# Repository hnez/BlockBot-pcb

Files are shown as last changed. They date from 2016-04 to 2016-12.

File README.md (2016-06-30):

BlockBot - Housing 3D-Designs
=============================

This repository contains all PCB design files.

All designs are created with the KiCad EDA suite.

The directory structure is as follow:

- blocks - Brick PCB
- dk_base - Millable PCB for the "denmark base" robot
- panel - Panelized layout that combines bricks and remote into a single file for cheaper ordering
- remote - Collector unit PCB

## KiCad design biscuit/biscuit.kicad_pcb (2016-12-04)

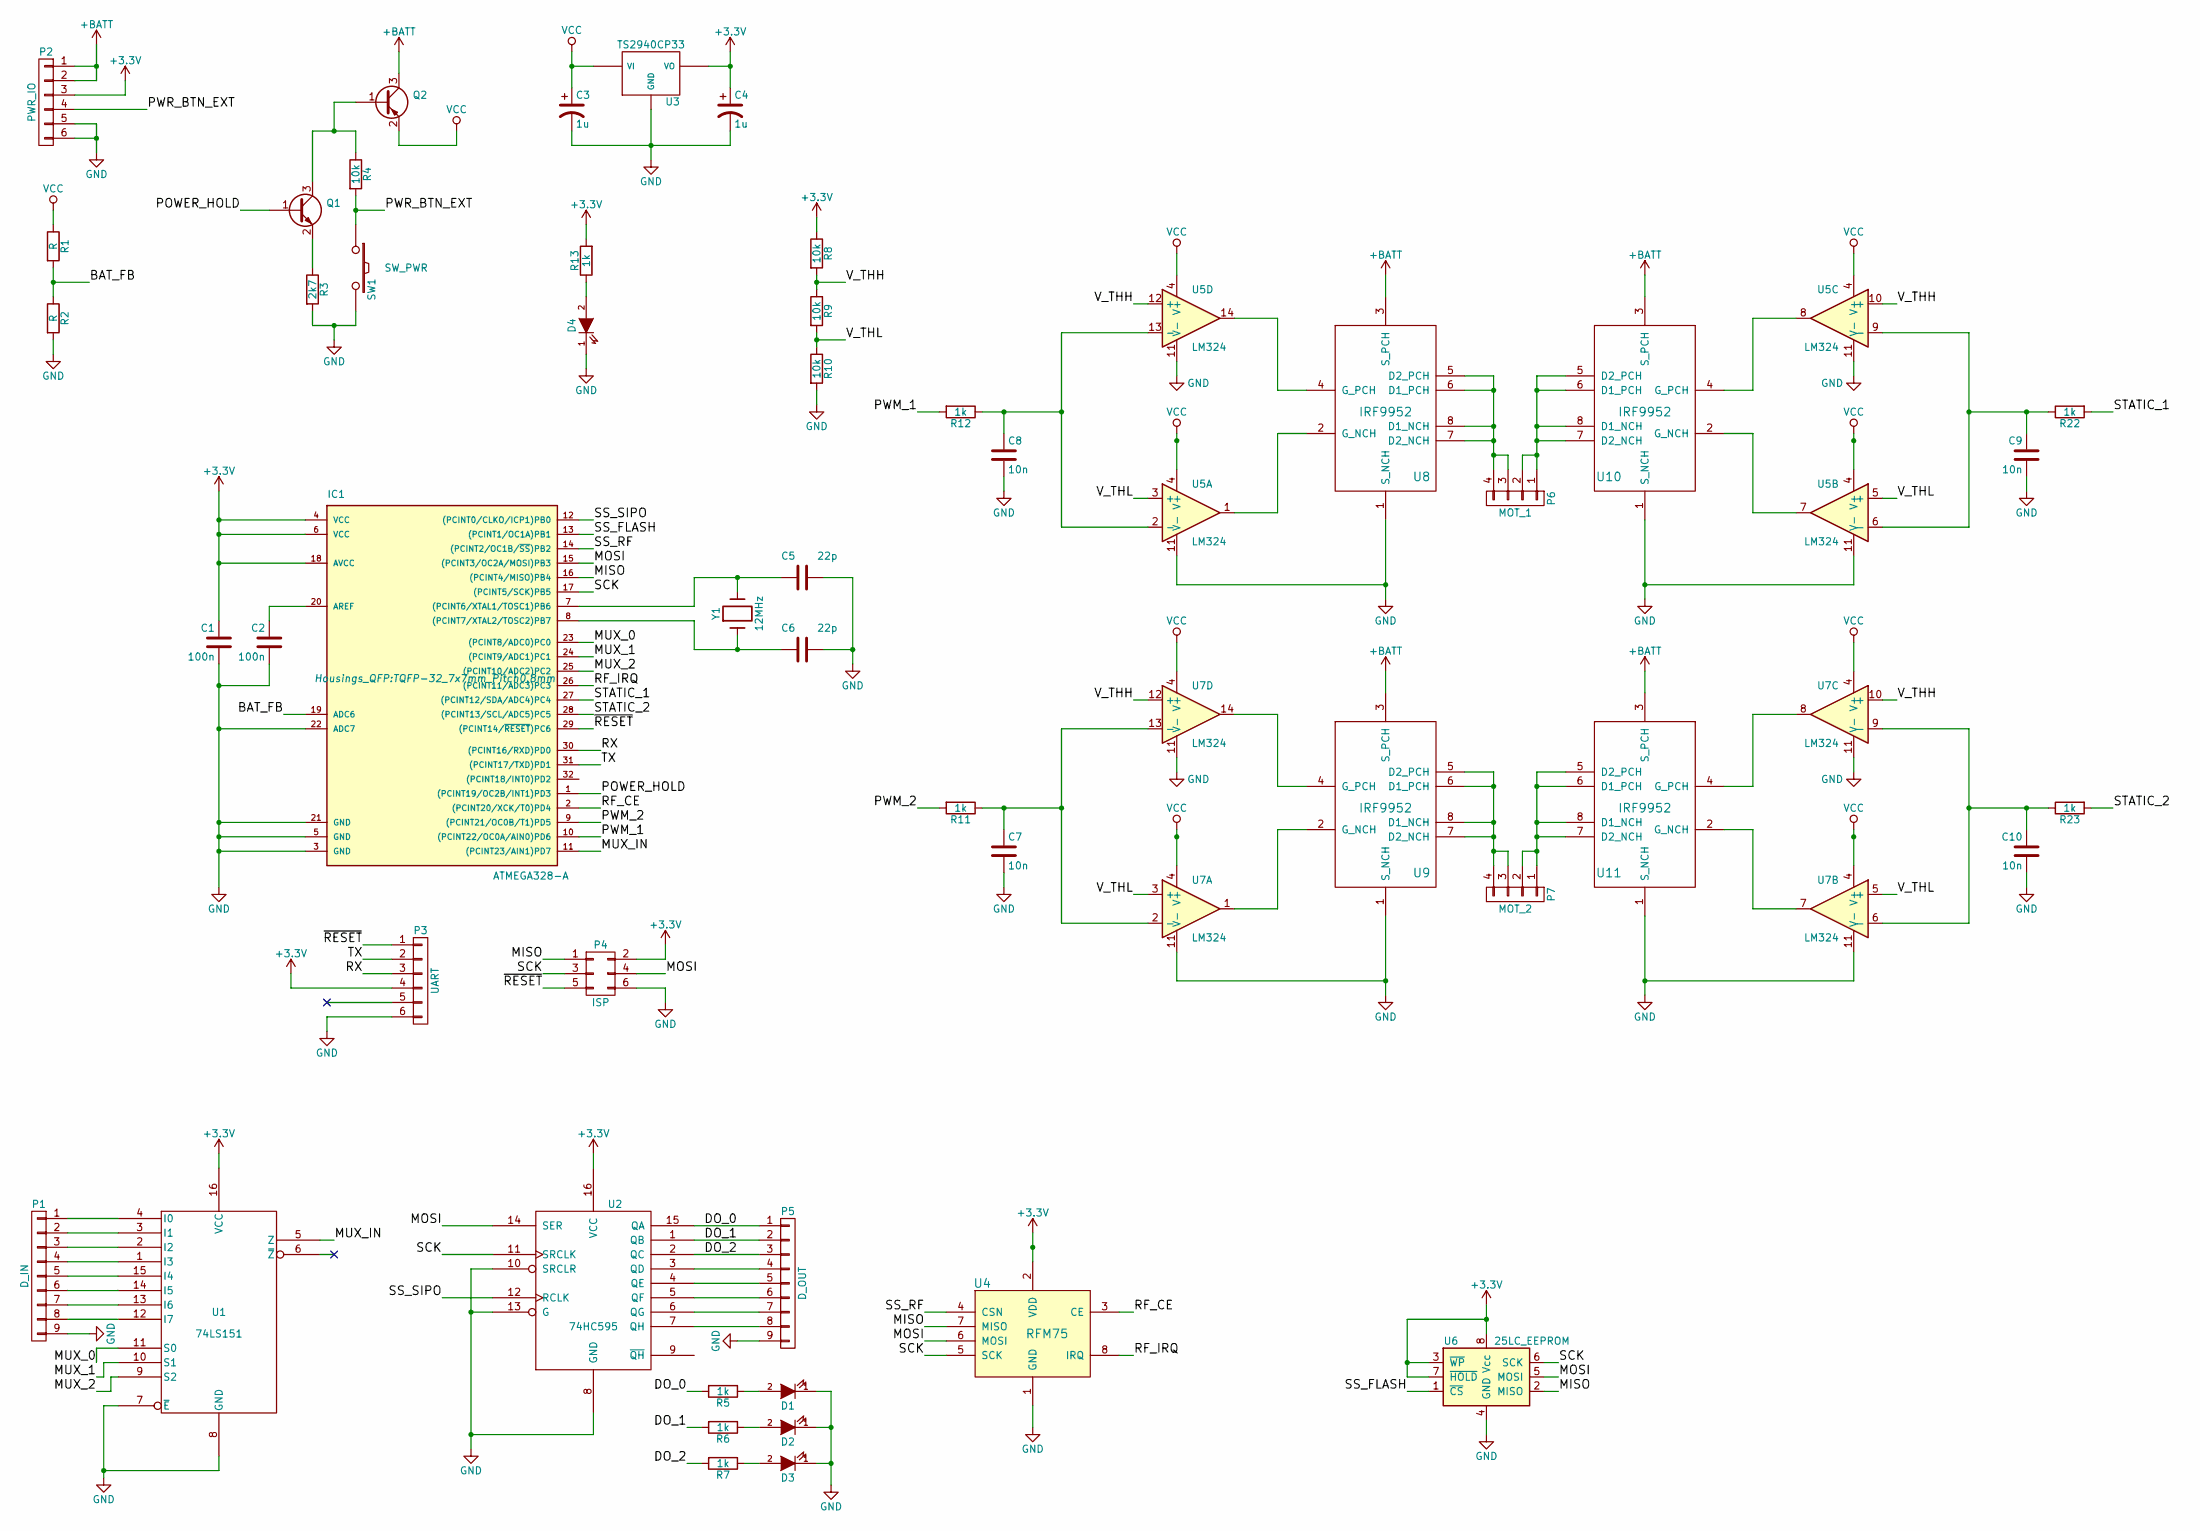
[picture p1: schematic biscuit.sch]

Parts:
C1, C2: 100n; C_0805
C3, C4: 1u; TantalC_SizeA_EIA-3216_Reflow
C5, C6: 22p; C_0805
C7, C8, C9, C10: 10n; C_0805
D1, D2, D3, D4: LED; LED_0805
IC1: ATMEGA328-A; TQFP-32_7x7mm_Pitch0.8mm
P1: D_IN; Pin_Header_Straight_1x09
P2: PWR_IO; Pin_Header_Straight_1x06
P3: UART; Pin_Header_Straight_1x06
P4: ISP; Pin_Header_Straight_2x03
P5: D_OUT; Pin_Header_Straight_1x09
P6: MOT_1; Pin_Header_Straight_1x04
P7: MOT_2; Pin_Header_Straight_1x04
Q1: Q_NPN_BEC; SOT-23
Q2: Q_PNP_BEC; SOT-23
R1, R2: R; R_0805
R3: 2k7; R_0805
R4, R8, R9, R10: 10k; R_0805
R5, R6, R7, R11, R12, R13, R22, R23: 1k; R_0805
SW1: SW_PWR; Schurter_LSG_1301
U1: 74LS151; SO-16-N
U2: 74HC595; SO-16-N
U3: TS2940CP33; TO-252-2Lead
U4: RFM75
U5, U7: LM324; SOIC-14_N
U6: 25LC_EEPROM; SOIC-8-N
U8, U9, U10, U11: IRF9952; SOIC-8-N
Y1: 12MHz; Crystal_HC49-SD_SMD

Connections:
+3V3: C1.1, C4.1, IC1.4 (VCC), IC1.6 (VCC), IC1.18 (AVCC), P2.3, P3.4, P4.2, R8.1, R13.2, U1.16 (VCC), U2.16 (VCC), U3.3 (VO), U4.2 (VDD), U6.3 (~WP), U6.7 (~HOLD), U6.8 (Vcc)
+BATT: P2.1, P2.2, Q2.3 (C), U8.3 (S_PCH), U9.3 (S_PCH), U10.3 (S_PCH), U11.3 (S_PCH)
/BAT_FB: IC1.19 (ADC6), R1.2, R2.1
/DO_0: P5.1, R5.2, U2.15 (QA)
/DO_1: P5.2, R6.2, U2.1 (QB)
/DO_2: P5.3, R7.2, U2.2 (QC)
/MISO: IC1.16 ((PCINT4/MISO)PB4), P4.1, U4.7 (MISO), U6.2 (MISO)
/MOSI: IC1.15 ((PCINT3/OC2A/MOSI)PB3), P4.4, U2.14 (SER), U4.6 (MOSI), U6.5 (MOSI)
/MUX_0: IC1.23 ((PCINT8/ADC0)PC0), U1.11 (S0)
/MUX_1: IC1.24 ((PCINT9/ADC1)PC1), U1.10 (S1)
/MUX_2: IC1.25 ((PCINT10/ADC2)PC2), U1.9 (S2)
/MUX_IN: IC1.11 ((PCINT23/AIN1)PD7), U1.5 (Z)
/POWER_HOLD: IC1.1 ((PCINT19/OC2B/INT1)PD3), Q1.1 (B)
/PWM_1: IC1.10 ((PCINT22/OC0A/AIN0)PD6), R12.2
/PWM_2: IC1.9 ((PCINT21/OC0B/T1)PD5), R11.2
/PWR_BTN_EXT: P2.4, R4.2, SW1.1
/RF_CE: IC1.2 ((PCINT20/XCK/T0)PD4), U4.3 (CE)
/RF_IRQ: IC1.26 ((PCINT11/ADC3)PC3), U4.8 (IRQ)
/RX: IC1.30 ((PCINT16/RXD)PD0), P3.3
/SCK: IC1.17 ((PCINT5/SCK)PB5), P4.3, U2.11 (SRCLK), U4.5 (SCK), U6.6 (SCK)
/SS_FLASH: IC1.13 ((PCINT1/OC1A)PB1), U6.1 (~CS)
/SS_RF: IC1.14 ((PCINT2/OC1B/~SS~)PB2), U4.4 (CSN)
/SS_SIPO: IC1.12 ((PCINT0/CLKO/ICP1)PB0), U2.12 (RCLK)
/STATIC_1: IC1.27 ((PCINT12/SDA/ADC4)PC4), R22.2
/STATIC_2: IC1.28 ((PCINT13/SCL/ADC5)PC5), R23.2
/TX: IC1.31 ((PCINT17/TXD)PD1), P3.2
/V_THH: R8.2, R9.1, U5.10 (+), U5.12 (+), U7.10 (+), U7.12 (+)
/V_THL: R9.2, R10.1, U5.3 (+), U5.5 (+), U7.3 (+), U7.5 (+)
/~RESET: IC1.29 ((PCINT14/~RESET~)PC6), P3.1, P4.5
GND: C1.2, C2.2, C3.2, C4.2, C5.1, C6.1, C7.2, C8.2, C9.2, C10.2, D1.1 (K), D2.1 (K), D3.1 (K), D4.1 (K), IC1.3 (GND), IC1.5 (GND), IC1.21 (GND), IC1.22 (ADC7), P1.9, P2.5, P2.6, P3.6, P4.6, P5.9, R2.2, R3.2, R10.2, SW1.2, U1.7 (~E), U1.8 (GND), U2.8 (GND), U2.10 (SRCLR), U2.13 (G), U3.2 (GND), U4.1 (GND), U5.11 (V-), U6.4 (GND), U7.11 (V-), U8.1 (S_NCH), U9.1 (S_NCH), U10.1 (S_NCH), U11.1 (S_NCH)
unnamed: C2.1, IC1.20 (AREF)
unnamed: C5.2, IC1.7 ((PCINT6/XTAL1/TOSC1)PB6), Y1.2
unnamed: C6.2, IC1.8 ((PCINT7/XTAL2/TOSC2)PB7), Y1.1
unnamed: C7.1, R11.1, U7.2 (-), U7.13 (-)
unnamed: C8.1, R12.1, U5.2 (-), U5.13 (-)
unnamed: C9.1, R22.1, U5.6 (-), U5.9 (-)
unnamed: C10.1, R23.1, U7.6 (-), U7.9 (-)
unnamed: D1.2 (A), R5.1
unnamed: D2.2 (A), R6.1
unnamed: D3.2 (A), R7.1
unnamed: D4.2 (A), R13.1
unnamed: P1.1, U1.4 (I0)
unnamed: P1.2, U1.3 (I1)
unnamed: P1.3, U1.2 (I2)
unnamed: P1.4, U1.1 (I3)
unnamed: P1.5, U1.15 (I4)
unnamed: P1.6, U1.14 (I5)
unnamed: P1.7, U1.13 (I6)
unnamed: P1.8, U1.12 (I7)
unnamed: P5.4, U2.3 (QD)
unnamed: P5.5, U2.4 (QE)
unnamed: P5.6, U2.5 (QF)
unnamed: P5.7, U2.6 (QG)
unnamed: P5.8, U2.7 (QH)
unnamed: P6.1, P6.2, U10.5 (D2_PCH), U10.6 (D1_PCH), U10.7 (D2_NCH), U10.8 (D1_NCH)
unnamed: P6.3, P6.4, U8.5 (D2_PCH), U8.6 (D1_PCH), U8.7 (D2_NCH), U8.8 (D1_NCH)
unnamed: P7.1, P7.2, U11.5 (D2_PCH), U11.6 (D1_PCH), U11.7 (D2_NCH), U11.8 (D1_NCH)
unnamed: P7.3, P7.4, U9.5 (D2_PCH), U9.6 (D1_PCH), U9.7 (D2_NCH), U9.8 (D1_NCH)
unnamed: Q1.2 (E), R3.1
unnamed: Q1.3 (C), Q2.1 (B), R4.1
unnamed: U5.1, U8.2 (G_NCH)
unnamed: U5.14, U8.4 (G_PCH)
unnamed: U7.1, U9.2 (G_NCH)
unnamed: U7.14, U9.4 (G_PCH)
unnamed: U5.7, U10.2 (G_NCH)
unnamed: U5.8, U10.4 (G_PCH)
unnamed: U7.7, U11.2 (G_NCH)
unnamed: U7.8, U11.4 (G_PCH)
VCC: C3.1, Q2.2 (E), R1.1, U3.1 (VI), U5.4 (V+), U7.4 (V+)

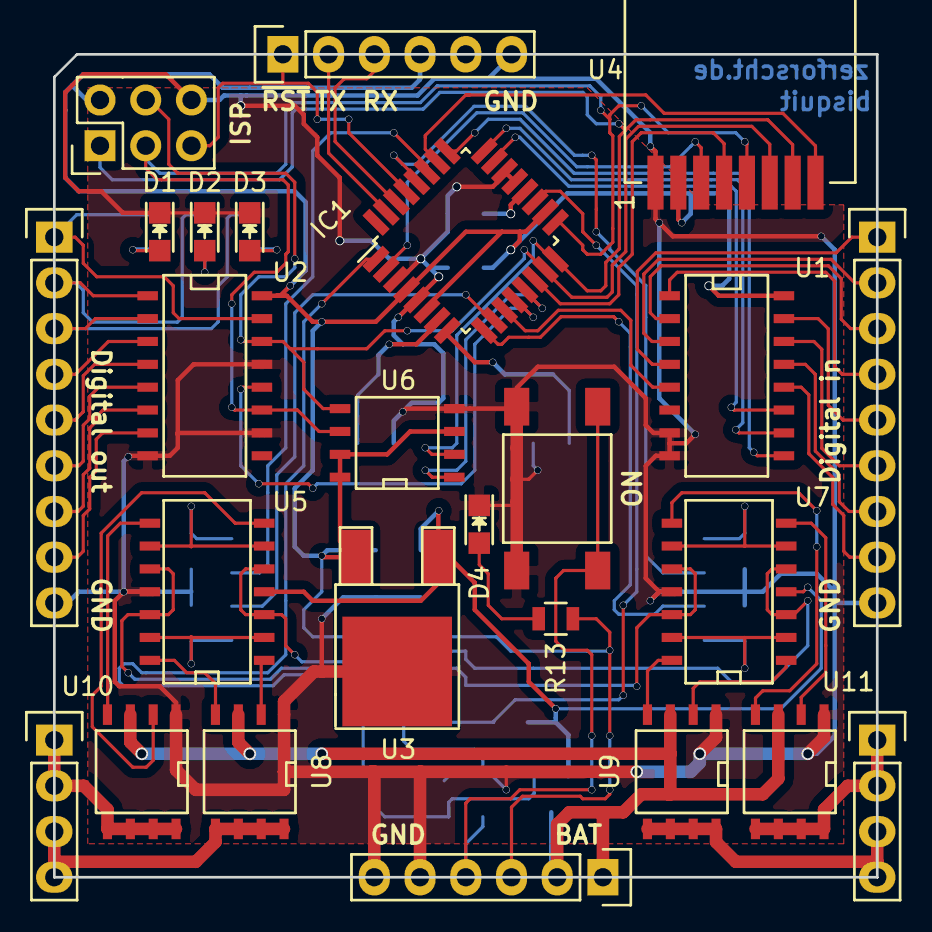
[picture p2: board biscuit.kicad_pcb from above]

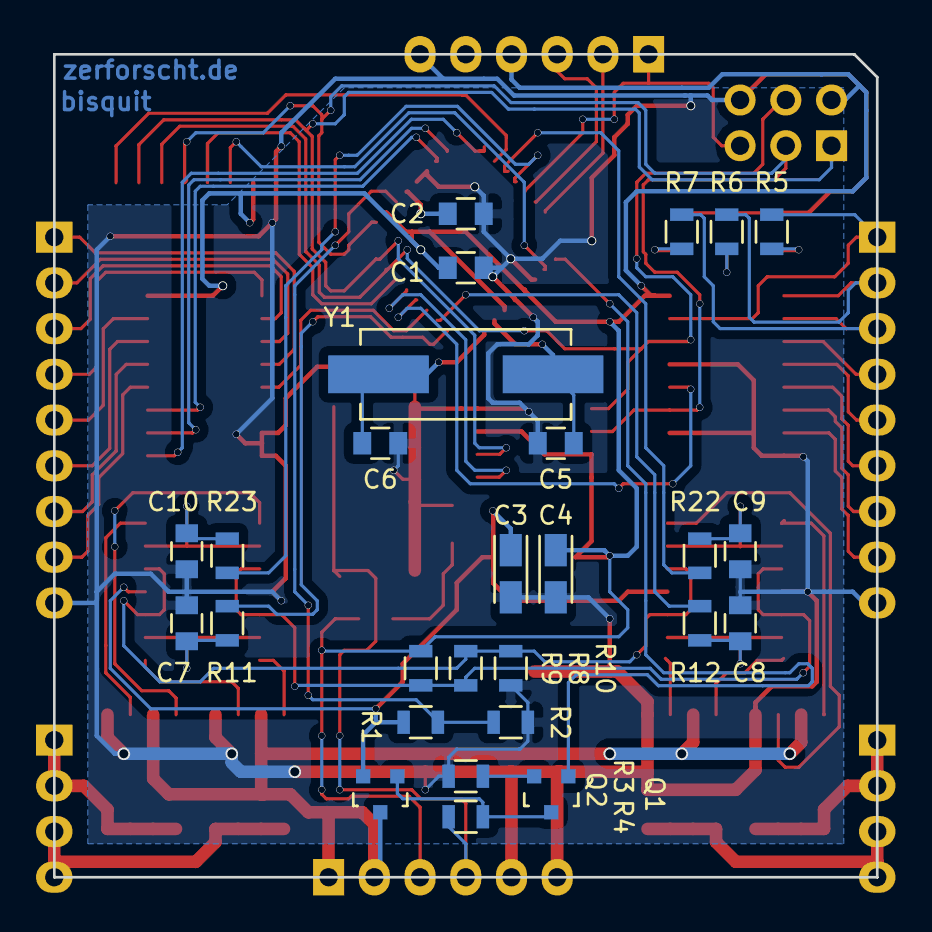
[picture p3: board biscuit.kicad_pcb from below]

Board: 2 copper layers, 45.7 x 45.7 mm, 52 parts (27 on the bottom side), 69 nets.

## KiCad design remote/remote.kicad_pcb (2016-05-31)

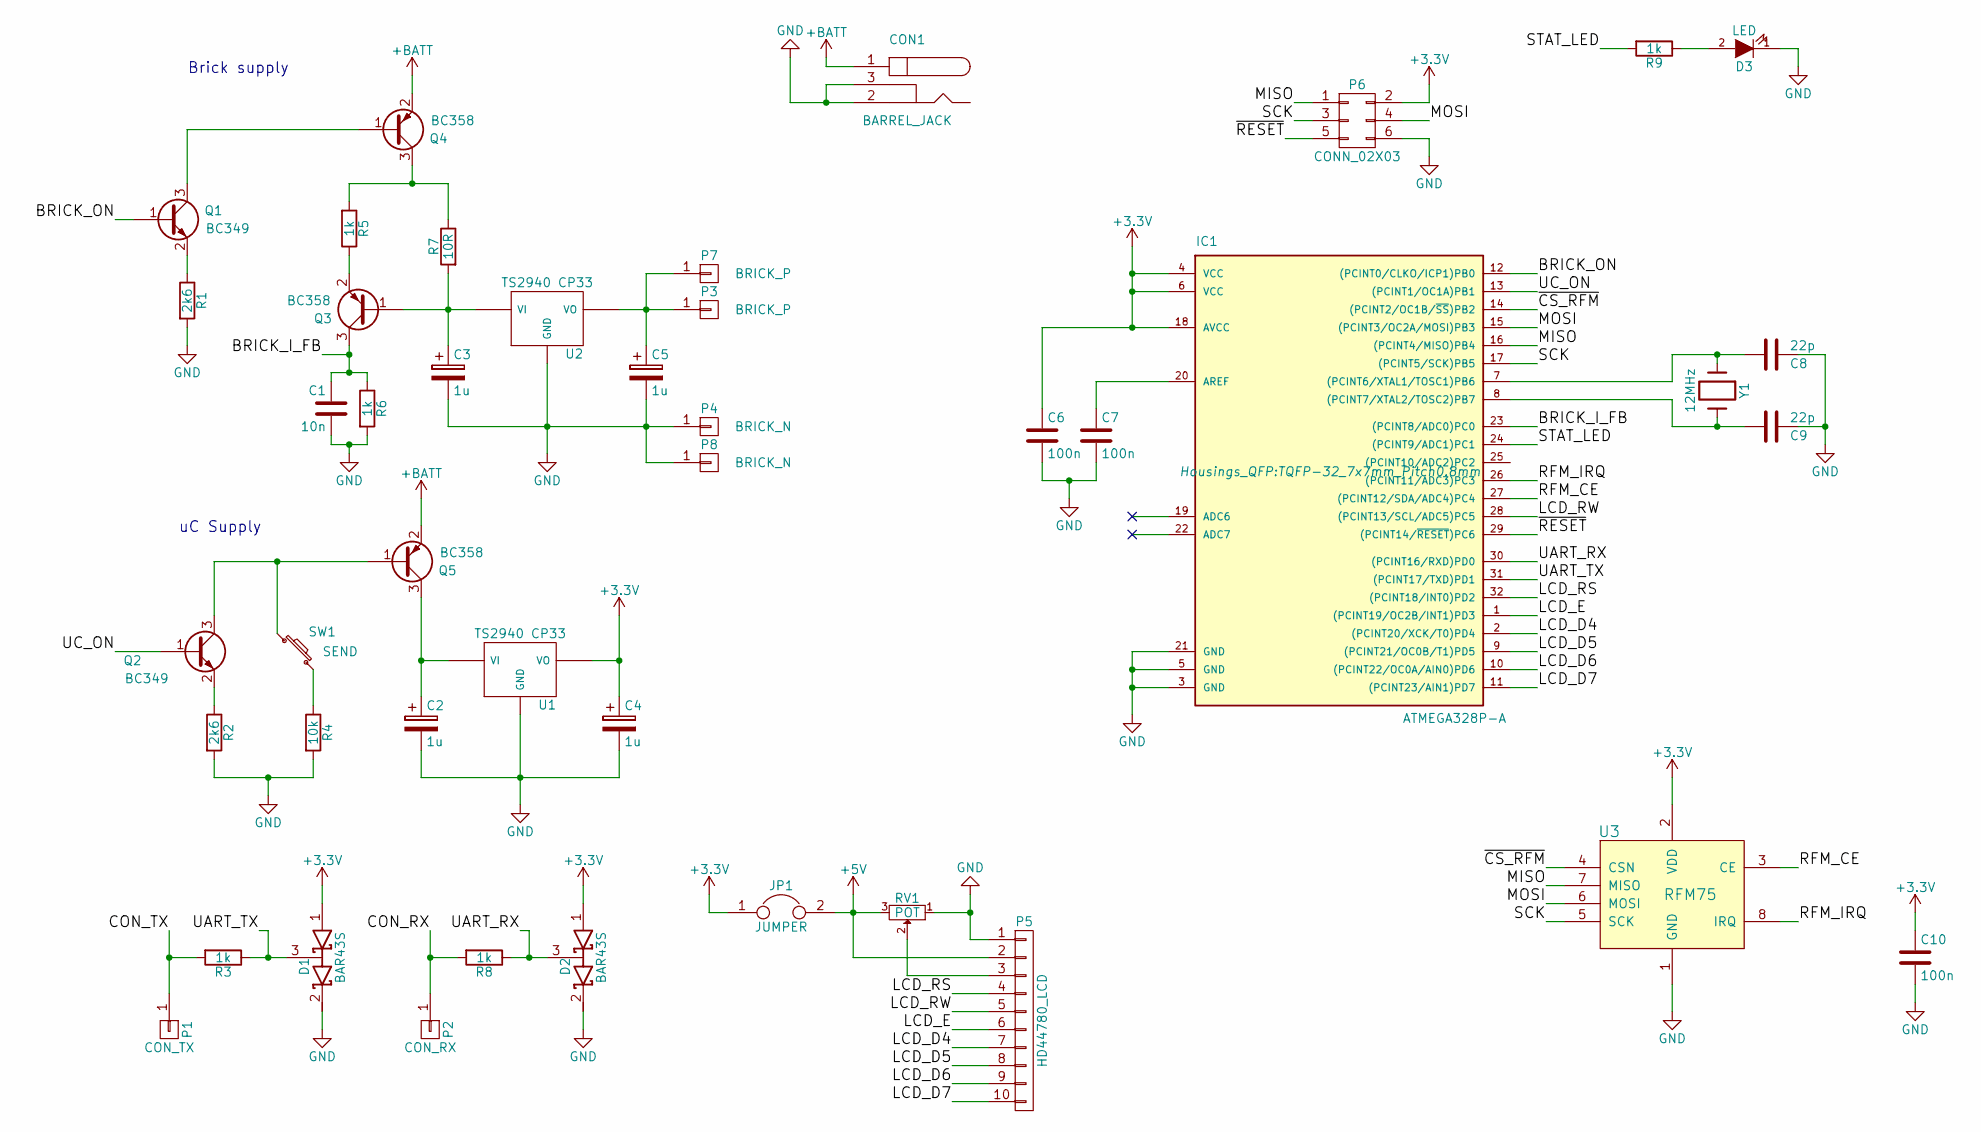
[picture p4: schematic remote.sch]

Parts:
C1: 10n; C_0805_HandSoldering
C2, C3, C4, C5: 1u; TantalC_SizeA_EIA-3216_HandSoldering
C6, C7, C10: 100n; C_0805_HandSoldering
C8, C9: 22p; C_0805_HandSoldering
CON1: BARREL_JACK
D1, D2: BAR43S; SOT-23
D3: LED; LED-3MM
IC1: ATMEGA328P-A; TQFP-32_7x7mm_Pitch0.8mm
JP1: JUMPER; R_0805_HandSoldering
P1: CON_TX; SmallFoilCon
P2: CON_RX; SmallFoilCon
P3, P7: BRICK_P; SmallFoilCon
P4, P8: BRICK_N; BigFoilCon
P5: HD44780_LCD; Pin_Header_Straight_1x10
P6: CONN_02X03; Pin_Header_Straight_2x03
Q1, Q2: BC349; SOT-23
Q3, Q4, Q5: BC358; SOT-23
R1, R2: 2k6; R_0805_HandSoldering
R3, R5, R6, R8, R9: 1k; R_0805_HandSoldering
R4: 10k; R_0805_HandSoldering
R7: 10R; R_0805_HandSoldering
RV1: POT; Cermet_Model23
SW1: SEND; Schurter_LSG_1301
U1, U2: TS2940 CP33; TO-252-2Lead
U3: RFM75
Y1: 12MHz; Crystal_HC49-U_Vertical

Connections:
+3V3: C4.1, C6.1, C10.1, D1.1 (A), D2.1 (A), IC1.4 (VCC), IC1.6 (VCC), IC1.18 (AVCC), JP1.1, P6.2, U1.VO, U3.2 (VDD)
+5V: JP1.2, P5.2, RV1.3
+BATT: CON1.1, Q4.2 (E), Q5.2 (E)
/BRICK_I_FB: C1.1, IC1.23 ((PCINT8/ADC0)PC0), Q3.3 (C), R6.1
/BRICK_ON: IC1.12 ((PCINT0/CLKO/ICP1)PB0), Q1.1 (B)
/CON_RX: P2.1, R8.2
/CON_TX: P1.1, R3.2
/LCD_D4: IC1.2 ((PCINT20/XCK/T0)PD4), P5.7
/LCD_D5: IC1.9 ((PCINT21/OC0B/T1)PD5), P5.8
/LCD_D6: IC1.10 ((PCINT22/OC0A/AIN0)PD6), P5.9
/LCD_D7: IC1.11 ((PCINT23/AIN1)PD7), P5.10
/LCD_E: IC1.1 ((PCINT19/OC2B/INT1)PD3), P5.6
/LCD_RS: IC1.32 ((PCINT18/INT0)PD2), P5.4
/LCD_RW: IC1.28 ((PCINT13/SCL/ADC5)PC5), P5.5
/MISO: IC1.16 ((PCINT4/MISO)PB4), P6.1, U3.7 (MISO)
/MOSI: IC1.15 ((PCINT3/OC2A/MOSI)PB3), P6.4, U3.6 (MOSI)
/RFM_CE: IC1.27 ((PCINT12/SDA/ADC4)PC4), U3.3 (CE)
/RFM_IRQ: IC1.26 ((PCINT11/ADC3)PC3), U3.8 (IRQ)
/SCK: IC1.17 ((PCINT5/SCK)PB5), P6.3, U3.5 (SCK)
/STAT_LED: IC1.24 ((PCINT9/ADC1)PC1), R9.2
/UART_RX: D2.3 (common), IC1.30 ((PCINT16/RXD)PD0), R8.1
/UART_TX: D1.3 (common), IC1.31 ((PCINT17/TXD)PD1), R3.1
/UC_ON: IC1.13 ((PCINT1/OC1A)PB1), Q2.1 (B)
/~CS_RFM: IC1.14 ((PCINT2/OC1B/~SS~)PB2), U3.4 (CSN)
/~RESET: IC1.29 ((PCINT14/~RESET~)PC6), P6.5
GND: C1.2, C2.2, C3.2, C4.2, C5.2, C6.2, C7.2, C8.1, C9.1, C10.2, CON1.2, CON1.3, D1.2 (K), D2.2 (K), D3.1 (K), IC1.3 (GND), IC1.5 (GND), IC1.21 (GND), P4.1, P5.1, P6.6, P8.1, R1.2, R2.2, R4.2, R6.2, RV1.1, U1.GND, U2.GND, U3.1 (GND)
unnamed: C2.1, Q5.3 (C), U1.VI
unnamed: C3.1, Q3.1 (B), R7.2, U2.VI
unnamed: C5.1, P3.1, P7.1, U2.VO
unnamed: C7.1, IC1.20 (AREF)
unnamed: C8.2, IC1.7 ((PCINT6/XTAL1/TOSC1)PB6), Y1.1
unnamed: C9.2, IC1.8 ((PCINT7/XTAL2/TOSC2)PB7), Y1.2
unnamed: D3.2 (A), R9.1
unnamed: P5.3, RV1.2
unnamed: Q1.2 (E), R1.1
unnamed: Q1.3 (C), Q4.1 (B)
unnamed: Q2.2 (E), R2.1
unnamed: Q2.3 (C), Q5.1 (B), SW1.1
unnamed: Q3.2 (E), R5.1
unnamed: Q4.3 (C), R5.2, R7.1
unnamed: R4.1, SW1.2

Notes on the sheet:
Brick supply
uC Supply

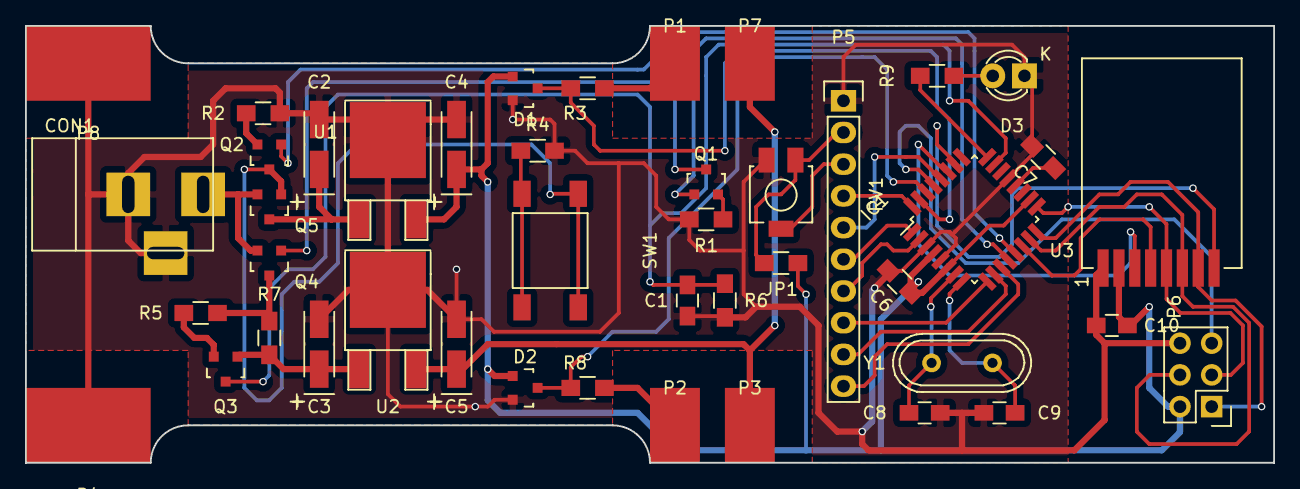
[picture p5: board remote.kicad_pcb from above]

Board: 2 copper layers, 100.0 x 35.0 mm, 44 parts (0 on the bottom side), 41 nets.

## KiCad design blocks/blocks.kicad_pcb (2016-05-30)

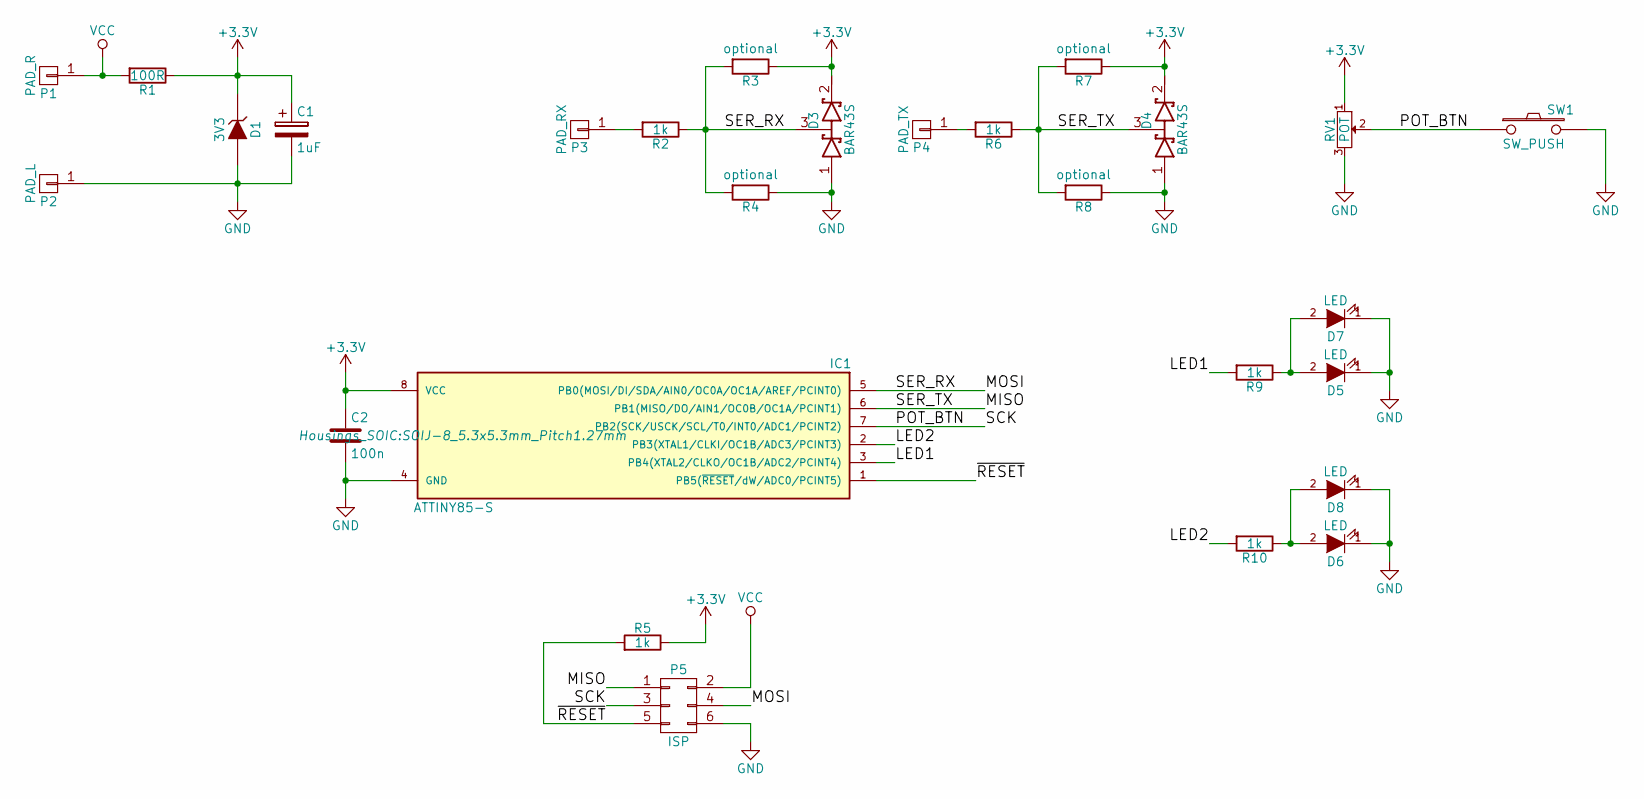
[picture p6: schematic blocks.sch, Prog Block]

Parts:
C1: 1uF; TantalC_SizeA_EIA-3216_HandSoldering
C2: 100n; C_0805_HandSoldering
D1: 3V3; SOT-23
D3, D4: BAR43S; SOT-23_Handsoldering
D5, D6: LED; LED-3MM
D7, D8: LED; LED_0805
IC1: ATTINY85-S; SOIJ-8_5.3x5.3mm_Pitch1.27mm
P1: PAD_R; BigPad
P2: PAD_L; HugePad
P3: PAD_RX; Smallpad
P4: PAD_TX; Smallpad
P5: ISP; Pin_Header_Straight_2x03
R1: 100R; R_0805_HandSoldering
R2, R5, R6, R9, R10: 1k; R_0805_HandSoldering
R3, R4, R7, R8: optional; R_0805_HandSoldering
RV1: POT; Cermet_Model23
SW1: SW_PUSH; Schurter_LSG_1301

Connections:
+3V3: C1.1, C2.1, D1.3 (K), D3.2 (K), D4.2 (K), IC1.8 (VCC), R1.1, R3.1, R5.1, R7.1, RV1.1
/LED1: IC1.3 (PB4(XTAL2/CLKO/OC1B/ADC2/PCINT4)), R9.2
/LED2: IC1.2 (PB3(XTAL1/CLKI/OC1B/ADC3/PCINT3)), R10.2
/MISO: D4.3 (common), IC1.6 (PB1(MISO/DO/AIN1/OC0B/OC1A/PCINT1)), P5.1, R6.1, R7.2, R8.2
/MOSI: D3.3 (common), IC1.5 (PB0(MOSI/DI/SDA/AIN0/OC0A/OC1A/AREF/PCI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), P5.4, R2.1, R3.2, R4.2
/POT_BTN: IC1.7 (PB2(SCK/USCK/SCL/T0/INT0/ADC1/PCINT2)), P5.3, RV1.2, SW1.1
/~RESET: IC1.1 (PB5(~RESET~/dW/ADC0/PCINT5)), P5.5, R5.2
GND: C1.2, C2.2, D1.1 (A), D3.1 (A), D4.1 (A), D5.1 (K), D6.1 (K), D7.1 (K), D8.1 (K), IC1.4 (GND), P2.1, P5.6, R4.1, R8.1, RV1.3, SW1.2
unnamed: D5.2 (A), D7.2 (A), R9.1
unnamed: D6.2 (A), D8.2 (A), R10.1
unnamed: P3.1, R2.2
unnamed: P4.1, R6.2
VCC: P1.1, P5.2, R1.2

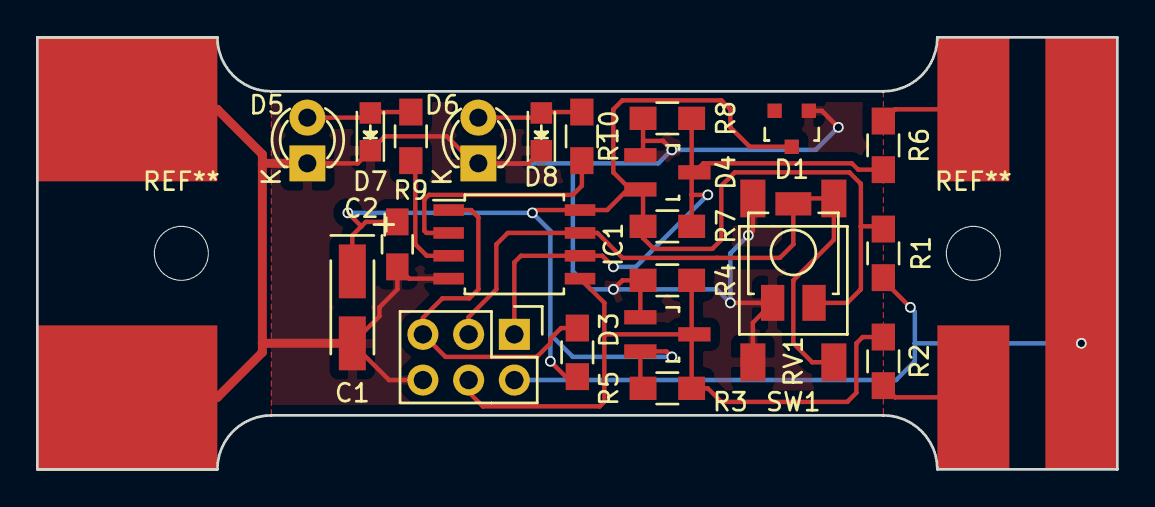
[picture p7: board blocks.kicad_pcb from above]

Board: 2 copper layers, 60.0 x 24.0 mm, 27 parts (0 on the bottom side), 13 nets.

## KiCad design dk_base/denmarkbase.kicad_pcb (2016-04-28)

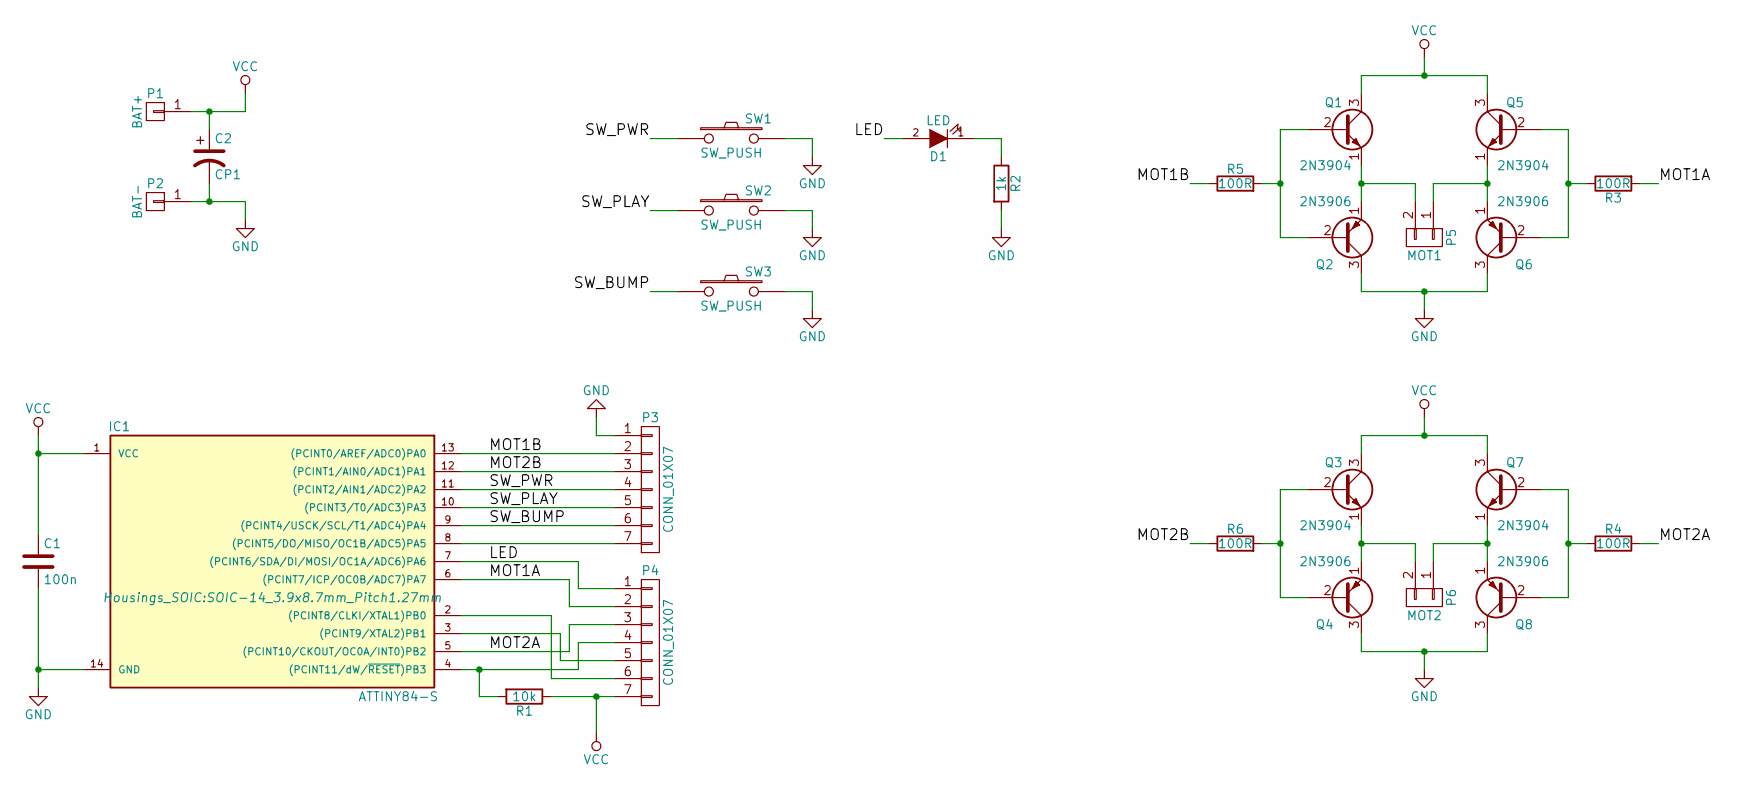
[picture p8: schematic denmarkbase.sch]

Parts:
C1: 100n; C_0805_HandSoldering
C2: CP1; C_Radial_D10_L16_P5
D1: LED; LED-3MM
IC1: ATTINY84-S; SOIC-14_3.9x8.7mm_Pitch1.27mm
P1: BAT+; BAT_CON
P2: BAT-; BAT_CON
P3, P4: CONN_01X07; Pin_Header_Straight_1x07
P5: MOT1; MOT
P6: MOT2; MOT
Q1, Q3, Q5, Q7: 2N3904; TO-92_Inline_Wide
Q2, Q4, Q6, Q8: 2N3906; TO-92_Inline_Wide
R1: 10k; Resistor_Horizontal_RM7mm
R2: 1k; Resistor_Horizontal_RM7mm
R3, R4, R5, R6: 100R; Resistor_Horizontal_RM7mm
SW1, SW2: SW_PUSH; BTN
SW3: SW_PUSH

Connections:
/LED: D1.2 (A), IC1.7 ((PCINT6/SDA/DI/MOSI/OC1A/ADC6)PA6), P4.1
/MOT1A: IC1.6 ((PCINT7/ICP/OC0B/ADC7)PA7), P4.2, R3.2
/MOT1B: IC1.13 ((PCINT0/AREF/ADC0)PA0), P3.2, R5.1
/MOT2A: IC1.5 ((PCINT10/CKOUT/OC0A/INT0)PB2), P4.3, R4.1
/MOT2B: IC1.12 ((PCINT1/AIN0/ADC1)PA1), P3.3, R6.1
/SW_BUMP: IC1.9 ((PCINT4/USCK/SCL/T1/ADC4)PA4), P3.6, SW3.1
/SW_PLAY: IC1.10 ((PCINT3/T0/ADC3)PA3), P3.5, SW2.1
/SW_PWR: IC1.11 ((PCINT2/AIN1/ADC2)PA2), P3.4, SW1.1
GND: C1.2, C2.2, IC1.14 (GND), P2.1, P3.1, Q2.3 (C), Q4.3 (C), Q6.3 (C), Q8.3 (C), R2.2, SW1.2, SW2.2, SW3.2
unnamed: D1.1 (K), R2.1
unnamed: IC1.2 ((PCINT8/CLKI/XTAL1)PB0), P4.6
unnamed: IC1.3 ((PCINT9/XTAL2)PB1), P4.5
unnamed: IC1.4 ((PCINT11/dW/~RESET~)PB3), P4.4, R1.2
unnamed: IC1.8 ((PCINT5/DO/MISO/OC1B/ADC5)PA5), P3.7
unnamed: P5.1, Q5.1 (E), Q6.1 (E)
unnamed: P5.2, Q1.1 (E), Q2.1 (E)
unnamed: P6.1, Q7.1 (E), Q8.1 (E)
unnamed: P6.2, Q3.1 (E), Q4.1 (E)
unnamed: Q1.2 (B), Q2.2 (B), R5.2
unnamed: Q3.2 (B), Q4.2 (B), R6.2
unnamed: Q5.2 (B), Q6.2 (B), R3.1
unnamed: Q7.2 (B), Q8.2 (B), R4.2
VCC: C1.1, C2.1, IC1.1 (VCC), P1.1, P4.7, Q1.3 (C), Q3.3 (C), Q5.3 (C), Q7.3 (C), R1.1

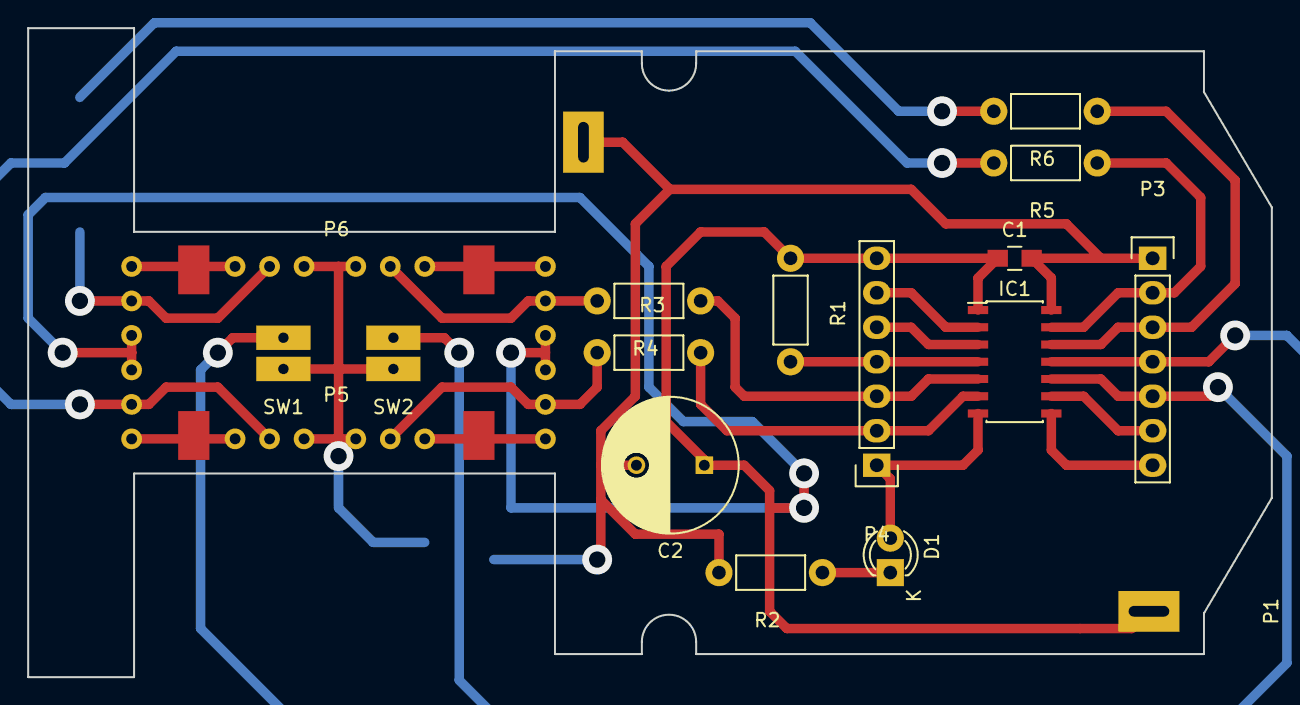
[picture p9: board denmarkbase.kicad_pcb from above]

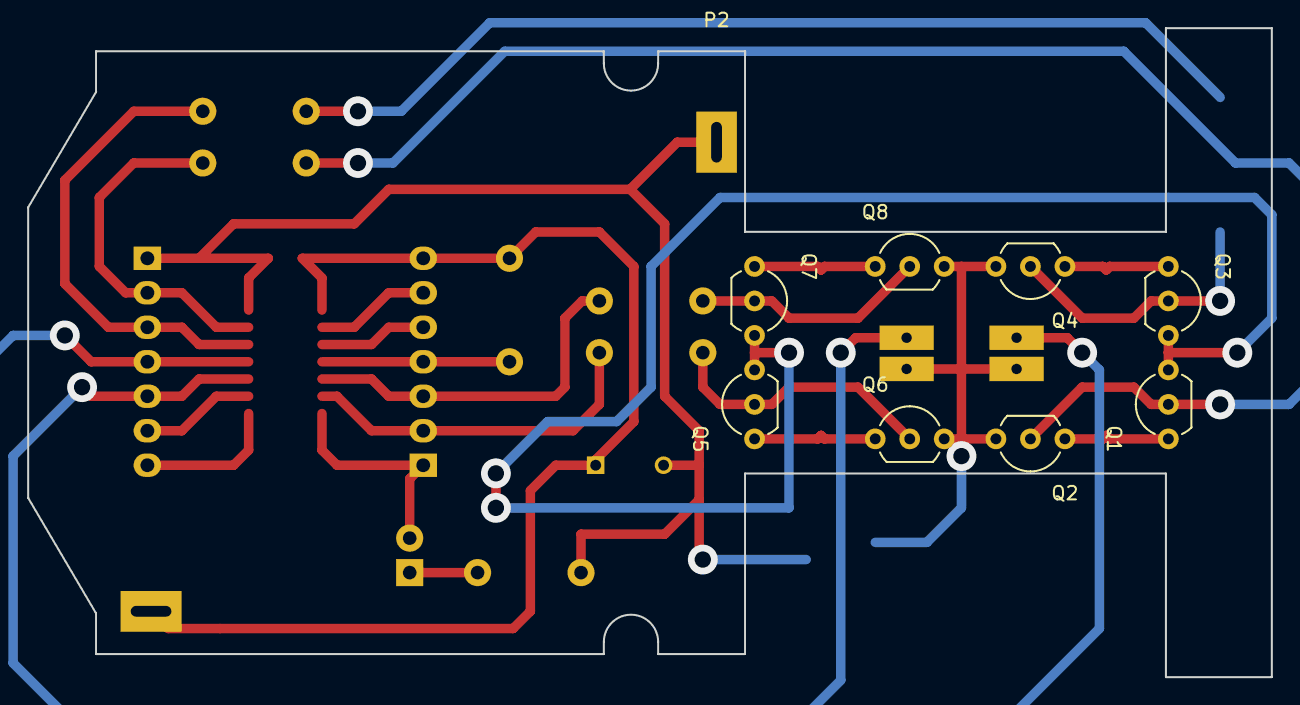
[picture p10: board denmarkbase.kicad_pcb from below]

Board: 2 copper layers, 91.6 x 47.8 mm, 26 parts (9 on the bottom side), 23 nets.

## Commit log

2016-04-24 Initial work on the block pcb
    [blocks.kicad_pcb, blocks.sch]
2016-04-24 Added name and domain to pcb
    [blocks.kicad_pcb, blocks.sch]
2016-04-25 Fixed wrong pull up reference for RESET input
    [blocks.kicad_pcb, blocks.sch]
2016-04-25 Started developing the remote control unit
    The Power supply for the blocks is overly complicated and batshit crazy.
    [remote.kicad_pcb, remote.sch]
2016-04-25 rationalized away one transistor
    [remote.sch]
2016-04-28 Designed a Millable PCB to retrofit a Existing robot base.
    [denmarkbase.kicad_pcb, denmarkbase.sch]
2016-04-28 Excluded Generated Gerber files from git
2016-05-30 Added mounting holes and changed Zener diode on brick pcb
    [blocks.kicad_pcb, blocks.sch]
2016-05-30 Started over again with the remote controll
    [remote.kicad_pcb, remote.sch]
2016-05-31 Collecor unit WIP
    [remote.kicad_pcb, remote.sch]
2016-05-31 finished layouting the collector unit
    [remote.kicad_pcb, remote.sch]
2016-05-31 Panelized design for ordering
    [panel.kicad_pcb]
2016-11-19 Started working on new robot meta platform "bisquit"
    [biscuit.kicad_pcb, biscuit.sch, mot_a.sch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]
2016-11-28 PCB Routing for bisquit
    [biscuit.kicad_pcb, biscuit.sch]
2016-12-04 First sucessful route for bisquit board
    [biscuit.kicad_pcb, biscuit.sch]
2016-12-04 Routing cleanup
    [biscuit.kicad_pcb]
2016-12-04 Cleanup labels and add power LED
    [biscuit.kicad_pcb, biscuit.sch]
2016-12-04 Added labels
    [biscuit.kicad_pcb]
2016-12-04 Added reference to website
    [biscuit.kicad_pcb, biscuit.sch]
